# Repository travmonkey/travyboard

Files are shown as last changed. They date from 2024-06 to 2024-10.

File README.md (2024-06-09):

# travyboard

## A corne style keyboard with the Pico SDK and TinyUSB

A personal project demonstrating how to build a keyboard using the 
Raspberry Pi Pico microcontroller in c++.

### Requirements

- Two Raspberry Pi Picos
- Cmake and gcc/g++ installed. May want to set up wsl2 on Windows.
- Pico SDK [GitHub Repo](https://github.com/raspberrypi/pico-sdk)

### Setup

1. Clone the Pico SDK and update the submodules
```sh
git clone https://github.com/raspberrypi/pico-sdk.git
cd pico-sdk
git submodule update --init
```

2. Set an environment variable so cmake can find the sdk
```sh
export PICO_SDK_PATH=`<pico sdk path>`
```

3. Clone this repository:
```sh
git clone https://github.com/travmonkey/travyboard.git
cd travyboard
```

4. Create build folder and build the project:
```sh
cd firmware
mkdir build && cd build
cmake -DCMAKE_EXPORT_COMPILE_COMMANDS=ON .. # Export the compile commands for clangd to see
make
```

5. Mount and flash both picos with the master and slave compiled .uf2 code.
```sh
mkdir ~/rpi-pico
sudo fdisk -l # Find the pico device
sudo mount /dev/sdx1 /home/`<user>`/rpi-pico
sudo cp src/master.uf2 /home/`<user>`/rpi-pico/
```
Alternativly you can modify the script I wrote to include your own directories and username

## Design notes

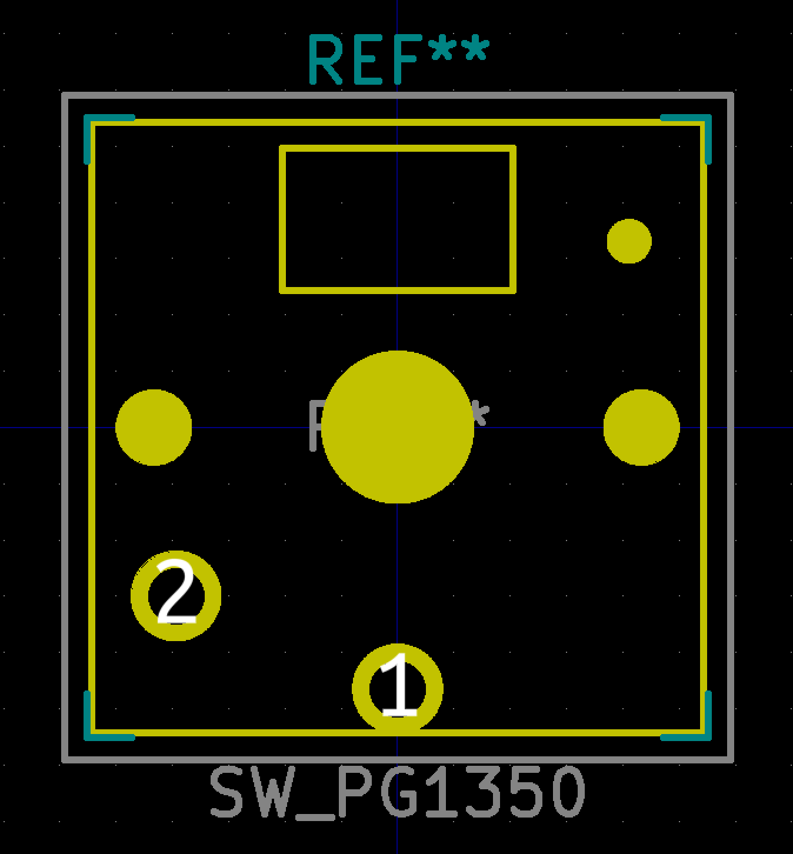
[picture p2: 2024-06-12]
pcb/symbols/keyswitches.pretty-2.1/images/SW_PG1350.png

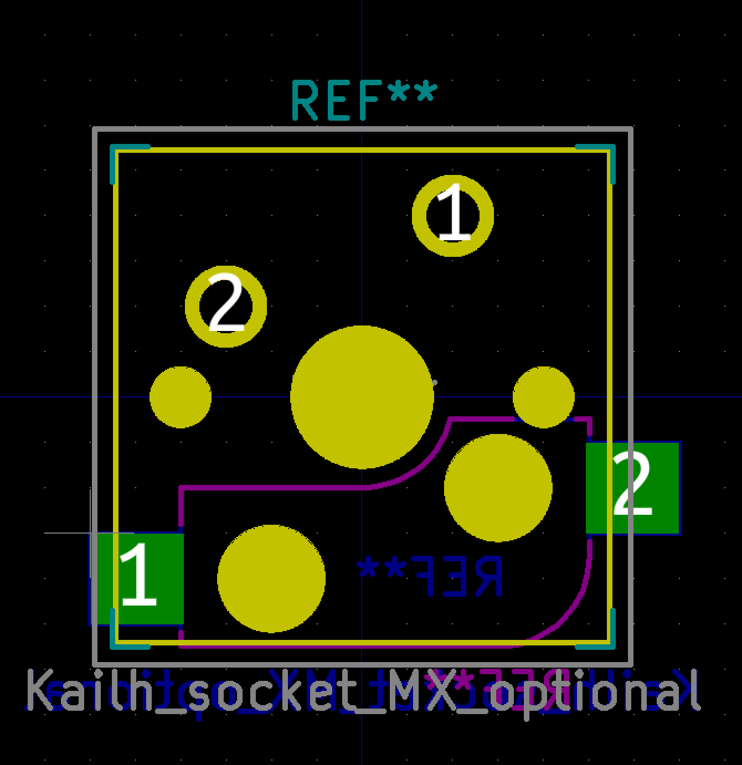
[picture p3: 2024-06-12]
pcb/symbols/keyswitches.pretty-2.1/images/Kailh_socket_MX_optional.png

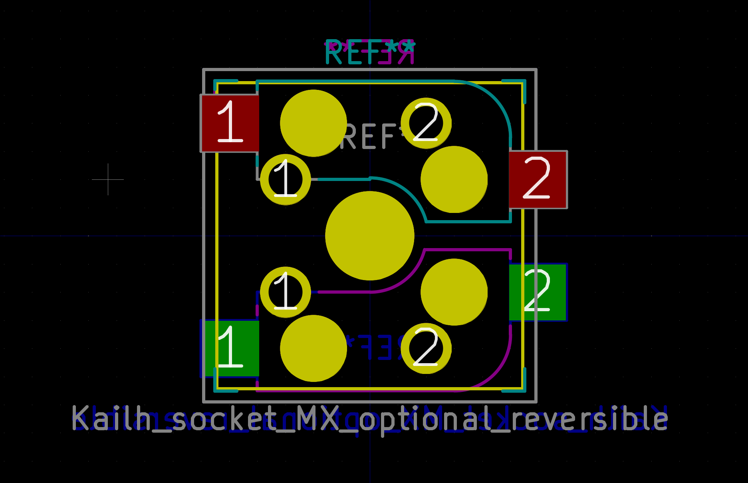
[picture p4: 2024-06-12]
pcb/symbols/keyswitches.pretty-2.1/images/Kailh_socket_MX_optional_reversible_platemount.png

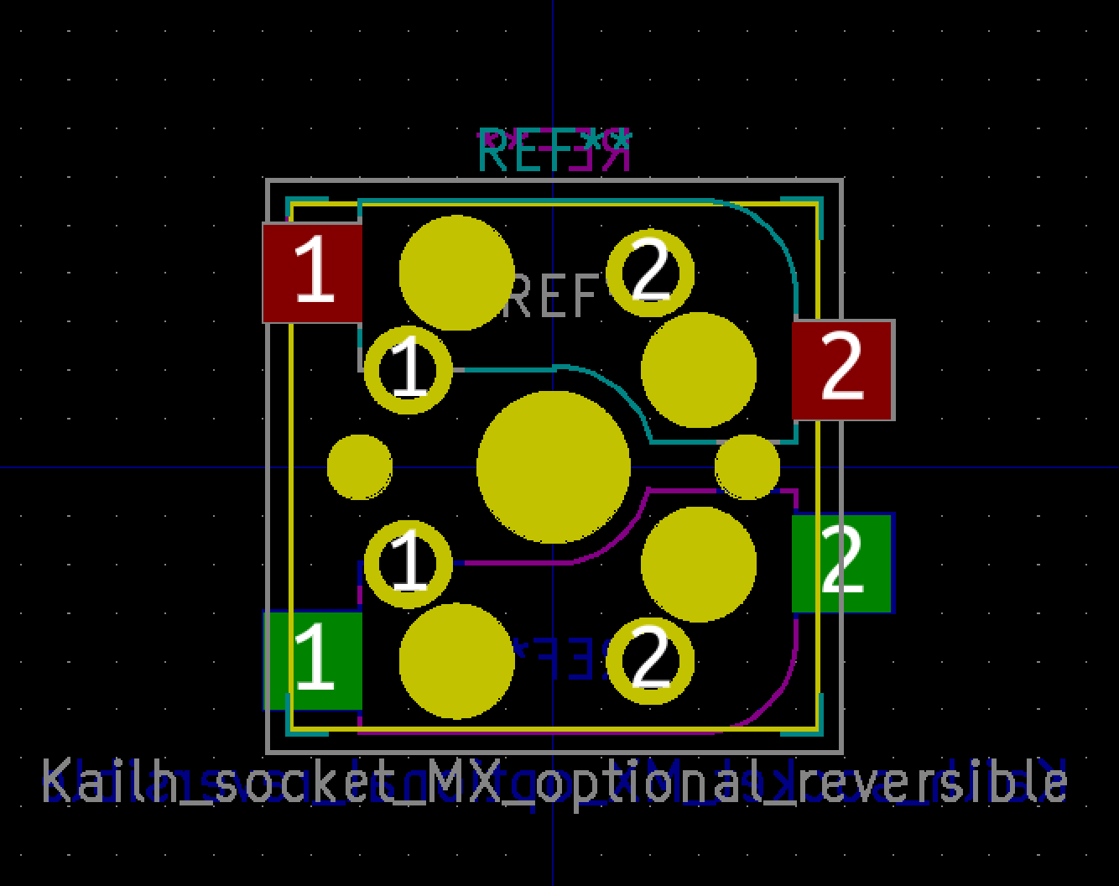
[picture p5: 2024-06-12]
pcb/symbols/keyswitches.pretty-2.1/images/Kailh_socket_MX_optional_reversible.png

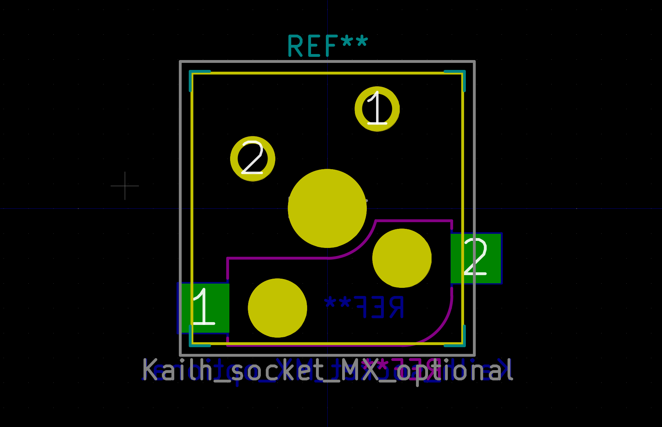
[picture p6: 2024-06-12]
pcb/symbols/keyswitches.pretty-2.1/images/Kailh_socket_MX_optional_platemount.png

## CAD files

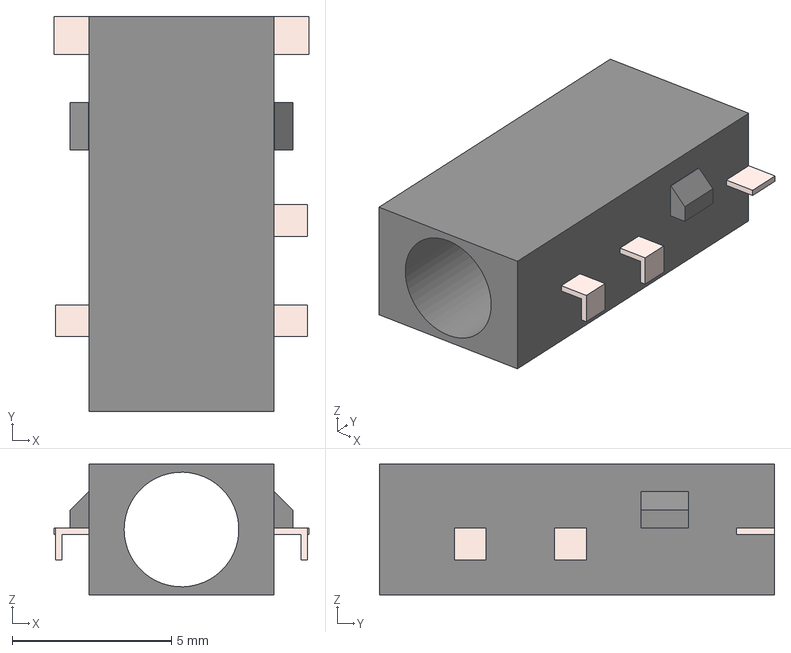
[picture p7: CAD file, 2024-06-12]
pcb/models/PJ-398A-5A.step
8.00 x 12.4 x 4.10 mm

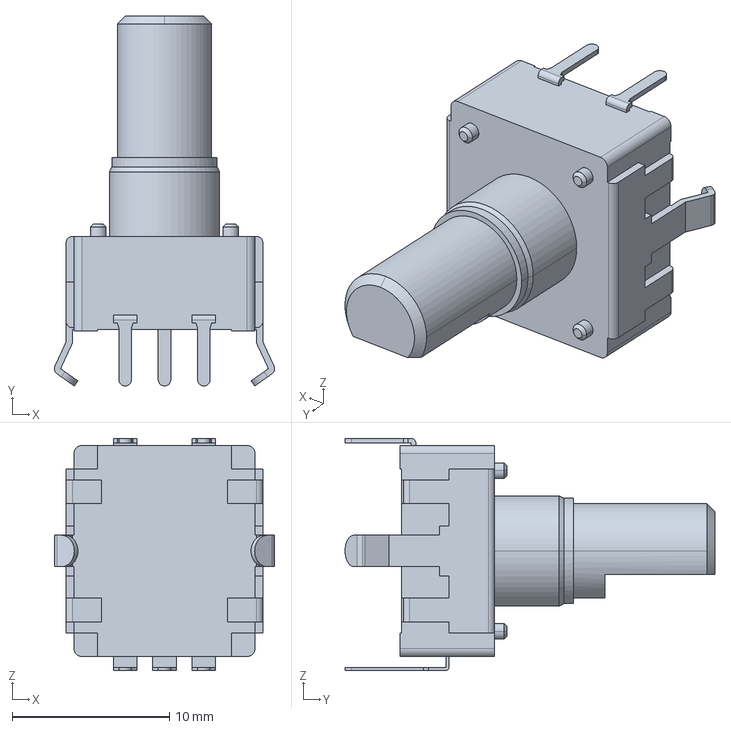
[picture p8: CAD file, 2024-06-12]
pcb/models/pec12r-4220f-s0024.stp
14.0 x 23.5 x 14.7 mm

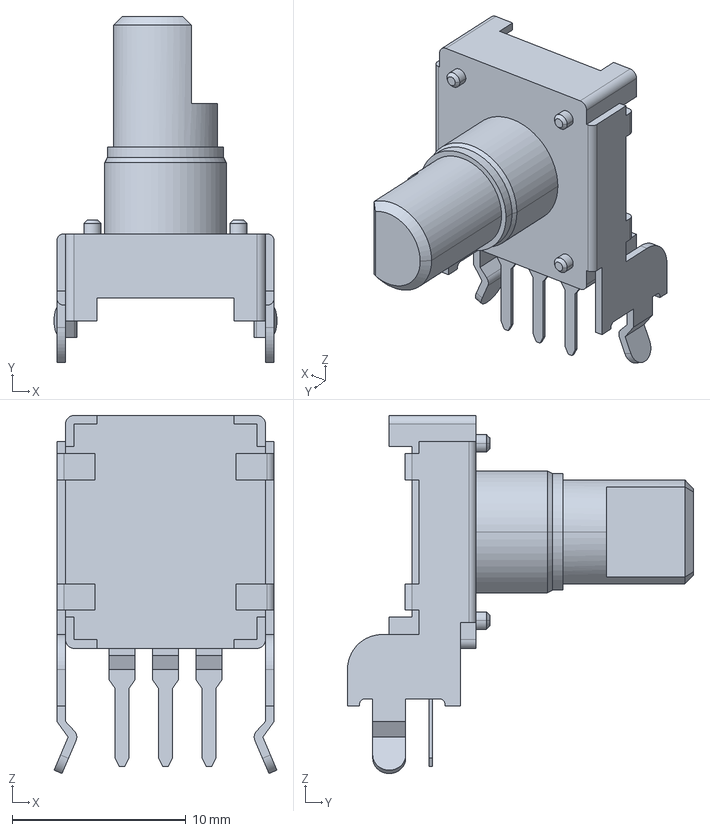
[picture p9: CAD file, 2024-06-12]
pcb/models/pec12r-2120f-s0012.stp
12.8 x 19.9 x 20.6 mm

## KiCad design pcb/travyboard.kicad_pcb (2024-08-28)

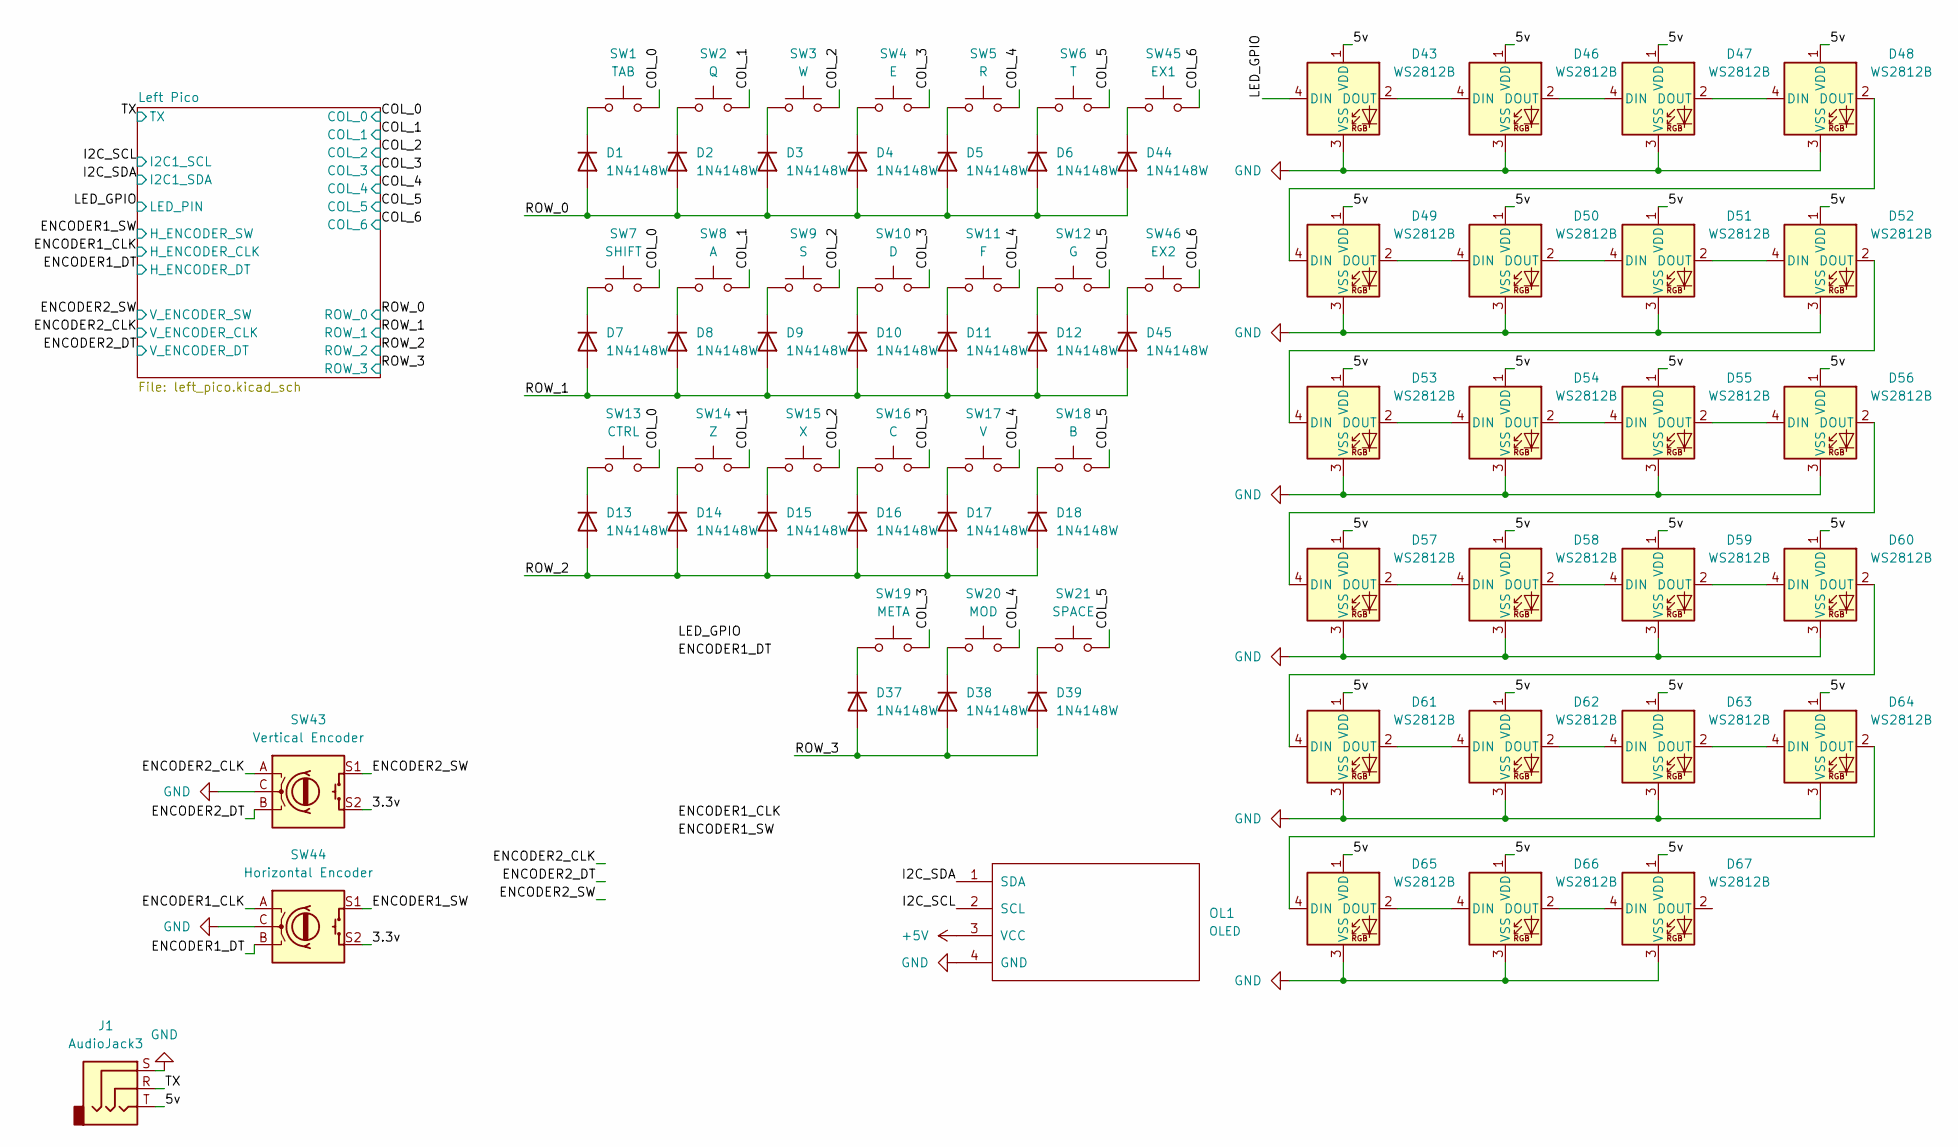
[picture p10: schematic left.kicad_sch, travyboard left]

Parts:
D1, D2, D3, D4, D5, D6, D7, D8, D9, D10, D11, D12, D13, D14, D15, D16, D17, D18, D37, D38, D39, D44, D45: 1N4148W; D_SOD-123
D43, D46, D47, D48, D49, D50, D51, D52, D53, D54, D55, D56, D57, D58, D59, D60, D61, D62, D63, D64, D65, D66, D67: WS2812B; LED_WS2812B_PLCC4_5.0x5.0mm_P3.2mm
J1: AudioJack3; PJ-399B-6A
OL1: OLED; SSD1306-0.91-OLED-4pin-128x32
SW1: TAB; CherryMX_Hotswap
SW2: Q; CherryMX_Hotswap
SW3: W; CherryMX_Hotswap
SW4: E; CherryMX_Hotswap
SW5: R; CherryMX_Hotswap
SW6: T; CherryMX_Hotswap
SW7: SHIFT; CherryMX_Hotswap
SW8: A; CherryMX_Hotswap
SW9: S; CherryMX_Hotswap
SW10: D; CherryMX_Hotswap
SW11: F; CherryMX_Hotswap
SW12: G; CherryMX_Hotswap
SW13: CTRL; CherryMX_Hotswap
SW14: Z; CherryMX_Hotswap
SW15: X; CherryMX_Hotswap
SW16: C; CherryMX_Hotswap
SW17: V; CherryMX_Hotswap
SW18: B; CherryMX_Hotswap
SW19: META; CherryMX_Hotswap
SW20: MOD; CherryMX_Hotswap
SW21: SPACE; CherryMX_Hotswap
SW43: Vertical Encoder; PEC12R-4220F-20024
SW44: Horizontal Encoder; PEC12R-2120F-S0012
SW45: EX1; CherryMX_Hotswap
SW46: EX2; CherryMX_Hotswap

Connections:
+5V: OL1.3 (VCC); also elsewhere on the board
/Left Half/3.3v: SW43.S2, SW44.S2
/Left Half/5v: D43.1 (VDD), D46.1 (VDD), D47.1 (VDD), D48.1 (VDD), D49.1 (VDD), D50.1 (VDD), D51.1 (VDD), D52.1 (VDD), D53.1 (VDD), D54.1 (VDD), D55.1 (VDD), D56.1 (VDD), D57.1 (VDD), D58.1 (VDD), D59.1 (VDD), D60.1 (VDD), D61.1 (VDD), D62.1 (VDD), D63.1 (VDD), D64.1 (VDD), D65.1 (VDD), D66.1 (VDD), D67.1 (VDD), J1.T
/Left Half/COL_0: SW1.2, SW7.2, SW13.2; also elsewhere on the board
/Left Half/COL_1: SW2.2, SW8.2, SW14.2; also elsewhere on the board
/Left Half/COL_2: SW3.2, SW9.2, SW15.2; also elsewhere on the board
/Left Half/COL_3: SW4.2, SW10.2, SW16.2, SW19.2; also elsewhere on the board
/Left Half/COL_4: SW5.2, SW11.2, SW17.2, SW20.2; also elsewhere on the board
/Left Half/COL_5: SW6.2, SW12.2, SW18.2, SW21.2; also elsewhere on the board
/Left Half/COL_6: SW45.2, SW46.2; also elsewhere on the board
/Left Half/ENCODER1_CLK: SW44.A; also elsewhere on the board
/Left Half/ENCODER1_DT: SW44.B; also elsewhere on the board
/Left Half/ENCODER1_SW: SW44.S1; also elsewhere on the board
/Left Half/ENCODER2_CLK: SW43.A; also elsewhere on the board
/Left Half/ENCODER2_DT: SW43.B; also elsewhere on the board
/Left Half/ENCODER2_SW: SW43.S1; also elsewhere on the board
/Left Half/I2C_SCL: OL1.2 (SCL); also elsewhere on the board
/Left Half/I2C_SDA: OL1.1 (SDA); also elsewhere on the board
/Left Half/LED_GPIO: D43.4 (DIN); also elsewhere on the board
/Left Half/ROW_0: D1.2 (A), D2.2 (A), D3.2 (A), D4.2 (A), D5.2 (A), D6.2 (A), D44.2 (A); also elsewhere on the board
/Left Half/ROW_1: D7.2 (A), D8.2 (A), D9.2 (A), D10.2 (A), D11.2 (A), D12.2 (A), D45.2 (A); also elsewhere on the board
/Left Half/ROW_2: D13.2 (A), D14.2 (A), D15.2 (A), D16.2 (A), D17.2 (A), D18.2 (A); also elsewhere on the board
/Left Half/ROW_3: D37.2 (A), D38.2 (A), D39.2 (A); also elsewhere on the board
/Left Half/TX: J1.R; also elsewhere on the board
GND: D43.3 (VSS), D46.3 (VSS), D47.3 (VSS), D48.3 (VSS), D49.3 (VSS), D50.3 (VSS), D51.3 (VSS), D52.3 (VSS), D53.3 (VSS), D54.3 (VSS), D55.3 (VSS), D56.3 (VSS), D57.3 (VSS), D58.3 (VSS), D59.3 (VSS), D60.3 (VSS), D61.3 (VSS), D62.3 (VSS), D63.3 (VSS), D64.3 (VSS), D65.3 (VSS), D66.3 (VSS), D67.3 (VSS), J1.S, OL1.4 (GND), SW43.C, SW44.C; also elsewhere on the board
unnamed: D1.1 (K), SW1.1
unnamed: D2.1 (K), SW2.1
unnamed: D3.1 (K), SW3.1
unnamed: D4.1 (K), SW4.1
unnamed: D5.1 (K), SW5.1
unnamed: D6.1 (K), SW6.1
unnamed: D7.1 (K), SW7.1
unnamed: D8.1 (K), SW8.1
unnamed: D9.1 (K), SW9.1
unnamed: D10.1 (K), SW10.1
unnamed: D11.1 (K), SW11.1
unnamed: D12.1 (K), SW12.1
unnamed: D13.1 (K), SW13.1
unnamed: D14.1 (K), SW14.1
unnamed: D15.1 (K), SW15.1
unnamed: D16.1 (K), SW16.1
unnamed: D17.1 (K), SW17.1
unnamed: D18.1 (K), SW18.1
unnamed: D37.1 (K), SW19.1
unnamed: D38.1 (K), SW20.1
unnamed: D39.1 (K), SW21.1
unnamed: D43.2 (DOUT), D46.4 (DIN)
unnamed: D44.1 (K), SW45.1
unnamed: D45.1 (K), SW46.1
unnamed: D46.2 (DOUT), D47.4 (DIN)
unnamed: D47.2 (DOUT), D48.4 (DIN)
unnamed: D48.2 (DOUT), D49.4 (DIN)
unnamed: D49.2 (DOUT), D50.4 (DIN)
unnamed: D50.2 (DOUT), D51.4 (DIN)
unnamed: D51.2 (DOUT), D52.4 (DIN)
unnamed: D52.2 (DOUT), D53.4 (DIN)
unnamed: D53.2 (DOUT), D54.4 (DIN)
unnamed: D54.2 (DOUT), D55.4 (DIN)
unnamed: D55.2 (DOUT), D56.4 (DIN)
unnamed: D56.2 (DOUT), D57.4 (DIN)
unnamed: D57.2 (DOUT), D58.4 (DIN)
unnamed: D58.2 (DOUT), D59.4 (DIN)
unnamed: D59.2 (DOUT), D60.4 (DIN)
unnamed: D60.2 (DOUT), D61.4 (DIN)
unnamed: D61.2 (DOUT), D62.4 (DIN)
unnamed: D62.2 (DOUT), D63.4 (DIN)
unnamed: D63.2 (DOUT), D64.4 (DIN)
unnamed: D64.2 (DOUT), D65.4 (DIN)
unnamed: D65.2 (DOUT), D66.4 (DIN)
unnamed: D66.2 (DOUT), D67.4 (DIN)

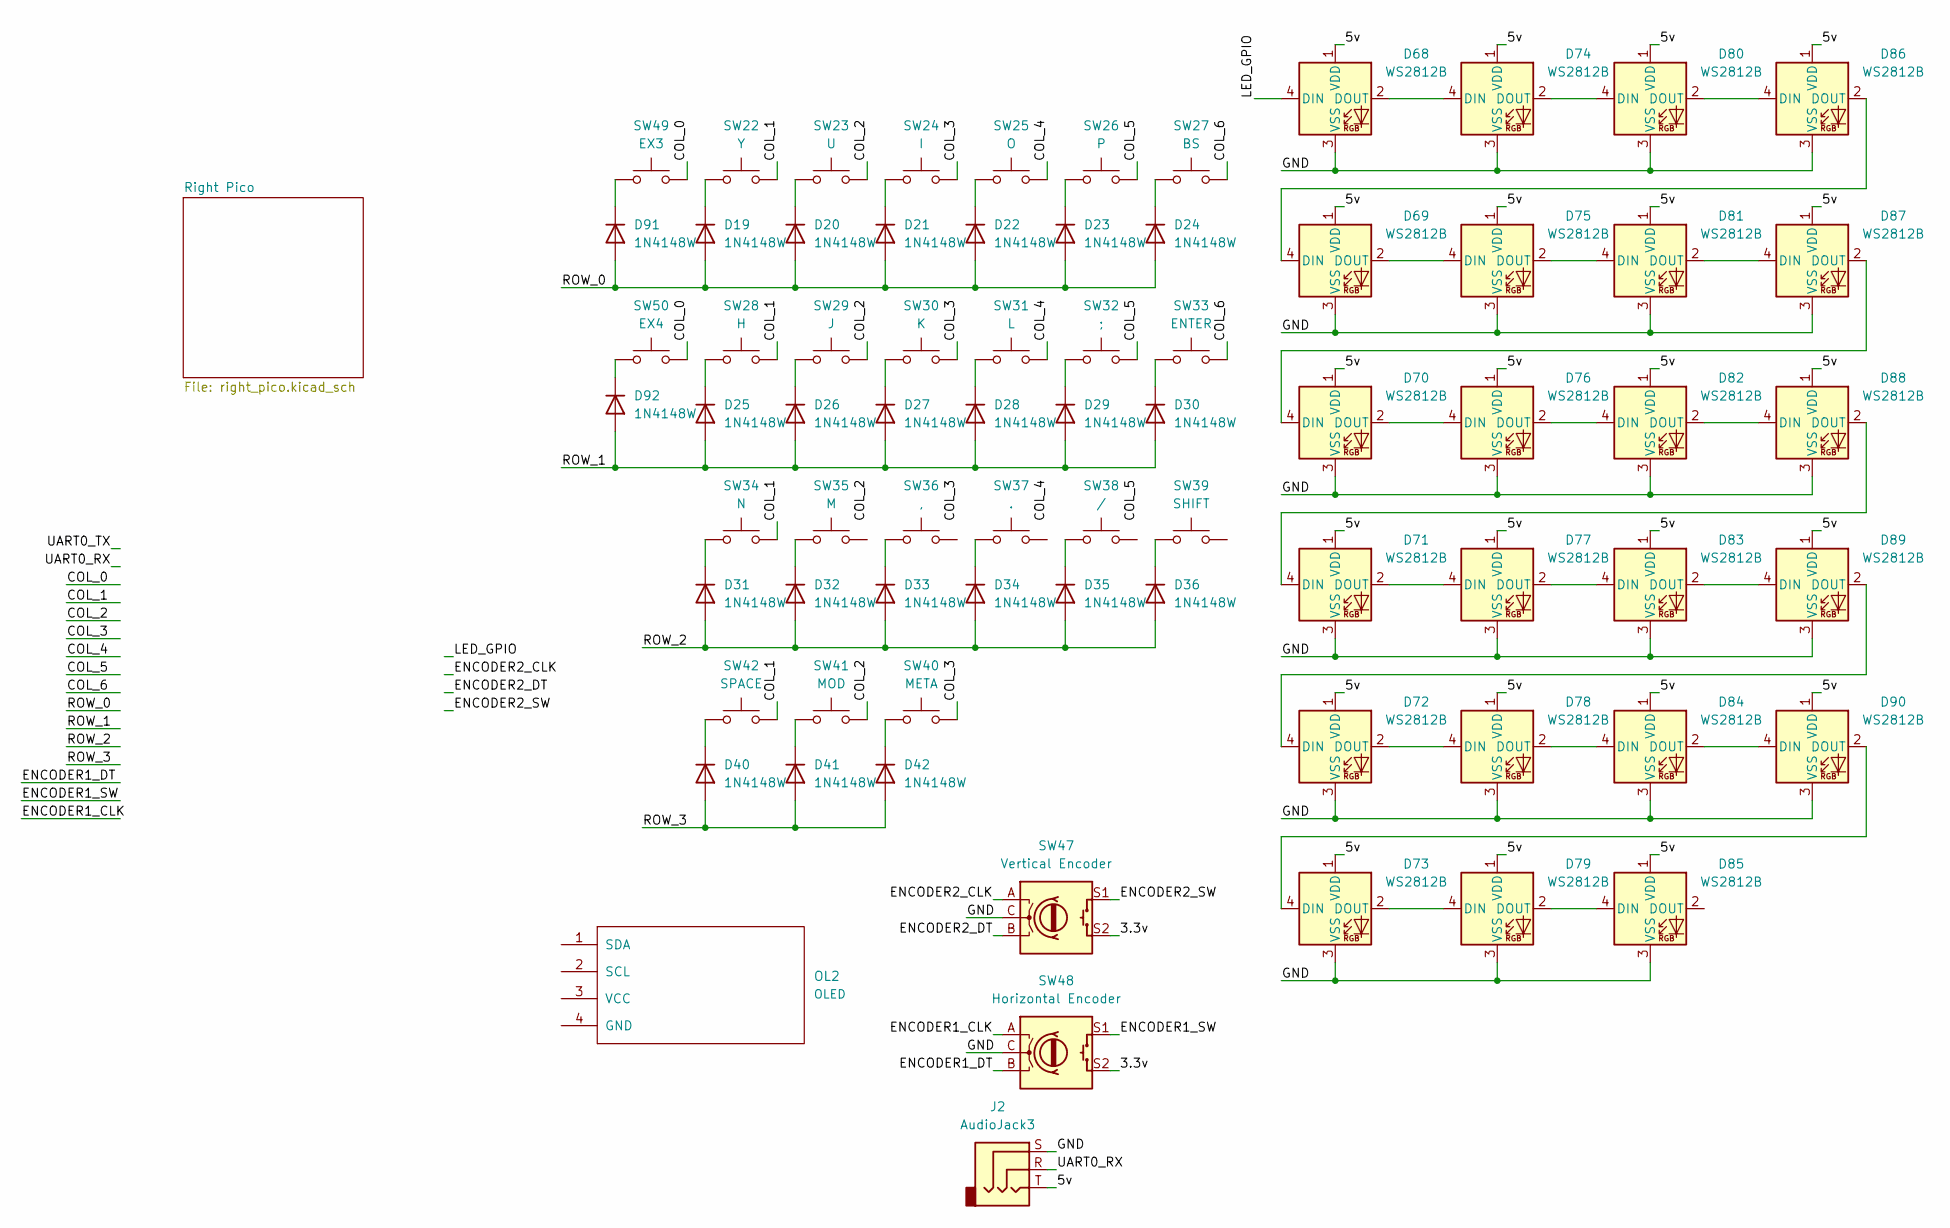
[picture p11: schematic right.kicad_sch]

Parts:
D19, D20, D21, D22, D23, D24, D25, D26, D27, D28, D29, D30, D31, D32, D33, D34, D35, D36, D40, D41, D42, D91, D92: 1N4148W; D_SOD-123
D68, D69, D70, D71, D72, D73, D74, D75, D76, D77, D78, D79, D80, D81, D82, D83, D84, D85, D86, D87, D88, D89, D90: WS2812B; LED_WS2812B_PLCC4_5.0x5.0mm_P3.2mm
J2: AudioJack3; PJ-399B-6A
OL2: OLED; SSD1306-0.91-OLED-4pin-128x32
SW22: Y; CherryMX_Hotswap
SW23: U; CherryMX_Hotswap
SW24: I; CherryMX_Hotswap
SW25: O; CherryMX_Hotswap
SW26: P; CherryMX_Hotswap
SW27: BS; CherryMX_Hotswap
SW28: H; CherryMX_Hotswap
SW29: J; CherryMX_Hotswap
SW30: K; CherryMX_Hotswap
SW31: L; CherryMX_Hotswap
SW32: ;; CherryMX_Hotswap
SW33: ENTER; CherryMX_Hotswap
SW34: N; CherryMX_Hotswap
SW35: M; CherryMX_Hotswap
SW36: ,; CherryMX_Hotswap
SW37: .; CherryMX_Hotswap
SW38: /; CherryMX_Hotswap
SW39: SHIFT; CherryMX_Hotswap
SW40: META; CherryMX_Hotswap
SW41: MOD; CherryMX_Hotswap
SW42: SPACE; CherryMX_Hotswap
SW47: Vertical Encoder; PEC12R-4220F-20024
SW48: Horizontal Encoder; PEC12R-2120F-S0012
SW49: EX3; CherryMX_Hotswap
SW50: EX4; CherryMX_Hotswap

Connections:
/Right Half/3.3v: SW47.S2, SW48.S2
/Right Half/5v: D68.1 (VDD), D69.1 (VDD), D70.1 (VDD), D71.1 (VDD), D72.1 (VDD), D73.1 (VDD), D74.1 (VDD), D75.1 (VDD), D76.1 (VDD), D77.1 (VDD), D78.1 (VDD), D79.1 (VDD), D80.1 (VDD), D81.1 (VDD), D82.1 (VDD), D83.1 (VDD), D84.1 (VDD), D85.1 (VDD), D86.1 (VDD), D87.1 (VDD), D88.1 (VDD), D89.1 (VDD), D90.1 (VDD), J2.T
/Right Half/COL_0: SW49.2, SW50.2
/Right Half/COL_1: SW22.2, SW28.2, SW34.2, SW42.2
/Right Half/COL_2: SW23.2, SW29.2, SW41.2
/Right Half/COL_3: SW24.2, SW30.2, SW40.2
/Right Half/COL_4: SW25.2, SW31.2
/Right Half/COL_5: SW26.2, SW32.2
/Right Half/COL_6: SW27.2, SW33.2
/Right Half/ENCODER1_CLK: SW48.A
/Right Half/ENCODER1_DT: SW48.B
/Right Half/ENCODER1_SW: SW48.S1
/Right Half/ENCODER2_CLK: SW47.A
/Right Half/ENCODER2_DT: SW47.B
/Right Half/ENCODER2_SW: SW47.S1
/Right Half/GND: D68.3 (VSS), D69.3 (VSS), D70.3 (VSS), D71.3 (VSS), D72.3 (VSS), D73.3 (VSS), D74.3 (VSS), D75.3 (VSS), D76.3 (VSS), D77.3 (VSS), D78.3 (VSS), D79.3 (VSS), D80.3 (VSS), D81.3 (VSS), D82.3 (VSS), D83.3 (VSS), D84.3 (VSS), D85.3 (VSS), D86.3 (VSS), D87.3 (VSS), D88.3 (VSS), D89.3 (VSS), D90.3 (VSS), J2.S, SW47.C, SW48.C
/Right Half/LED_GPIO: D68.4 (DIN)
/Right Half/ROW_0: D19.2 (A), D20.2 (A), D21.2 (A), D22.2 (A), D23.2 (A), D24.2 (A), D91.2 (A)
/Right Half/ROW_1: D25.2 (A), D26.2 (A), D27.2 (A), D28.2 (A), D29.2 (A), D30.2 (A), D92.2 (A)
/Right Half/ROW_2: D31.2 (A), D32.2 (A), D33.2 (A), D34.2 (A), D35.2 (A), D36.2 (A)
/Right Half/ROW_3: D40.2 (A), D41.2 (A), D42.2 (A)
/Right Half/UART0_RX: J2.R
unnamed: D19.1 (K), SW22.1
unnamed: D20.1 (K), SW23.1
unnamed: D21.1 (K), SW24.1
unnamed: D22.1 (K), SW25.1
unnamed: D23.1 (K), SW26.1
unnamed: D24.1 (K), SW27.1
unnamed: D25.1 (K), SW28.1
unnamed: D26.1 (K), SW29.1
unnamed: D27.1 (K), SW30.1
unnamed: D28.1 (K), SW31.1
unnamed: D29.1 (K), SW32.1
unnamed: D30.1 (K), SW33.1
unnamed: D31.1 (K), SW34.1
unnamed: D32.1 (K), SW35.1
unnamed: D33.1 (K), SW36.1
unnamed: D34.1 (K), SW37.1
unnamed: D35.1 (K), SW38.1
unnamed: D36.1 (K), SW39.1
unnamed: D40.1 (K), SW42.1
unnamed: D41.1 (K), SW41.1
unnamed: D42.1 (K), SW40.1
unnamed: D68.2 (DOUT), D74.4 (DIN)
unnamed: D69.4 (DIN), D86.2 (DOUT)
unnamed: D69.2 (DOUT), D75.4 (DIN)
unnamed: D70.4 (DIN), D87.2 (DOUT)
unnamed: D70.2 (DOUT), D76.4 (DIN)
unnamed: D71.4 (DIN), D88.2 (DOUT)
unnamed: D71.2 (DOUT), D77.4 (DIN)
unnamed: D72.4 (DIN), D89.2 (DOUT)
unnamed: D72.2 (DOUT), D78.4 (DIN)
unnamed: D73.4 (DIN), D90.2 (DOUT)
unnamed: D73.2 (DOUT), D79.4 (DIN)
unnamed: D74.2 (DOUT), D80.4 (DIN)
unnamed: D75.2 (DOUT), D81.4 (DIN)
unnamed: D76.2 (DOUT), D82.4 (DIN)
unnamed: D77.2 (DOUT), D83.4 (DIN)
unnamed: D78.2 (DOUT), D84.4 (DIN)
unnamed: D79.2 (DOUT), D85.4 (DIN)
unnamed: D80.2 (DOUT), D86.4 (DIN)
unnamed: D81.2 (DOUT), D87.4 (DIN)
unnamed: D82.2 (DOUT), D88.4 (DIN)
unnamed: D83.2 (DOUT), D89.4 (DIN)
unnamed: D84.2 (DOUT), D90.4 (DIN)
unnamed: D91.1 (K), SW49.1
unnamed: D92.1 (K), SW50.1

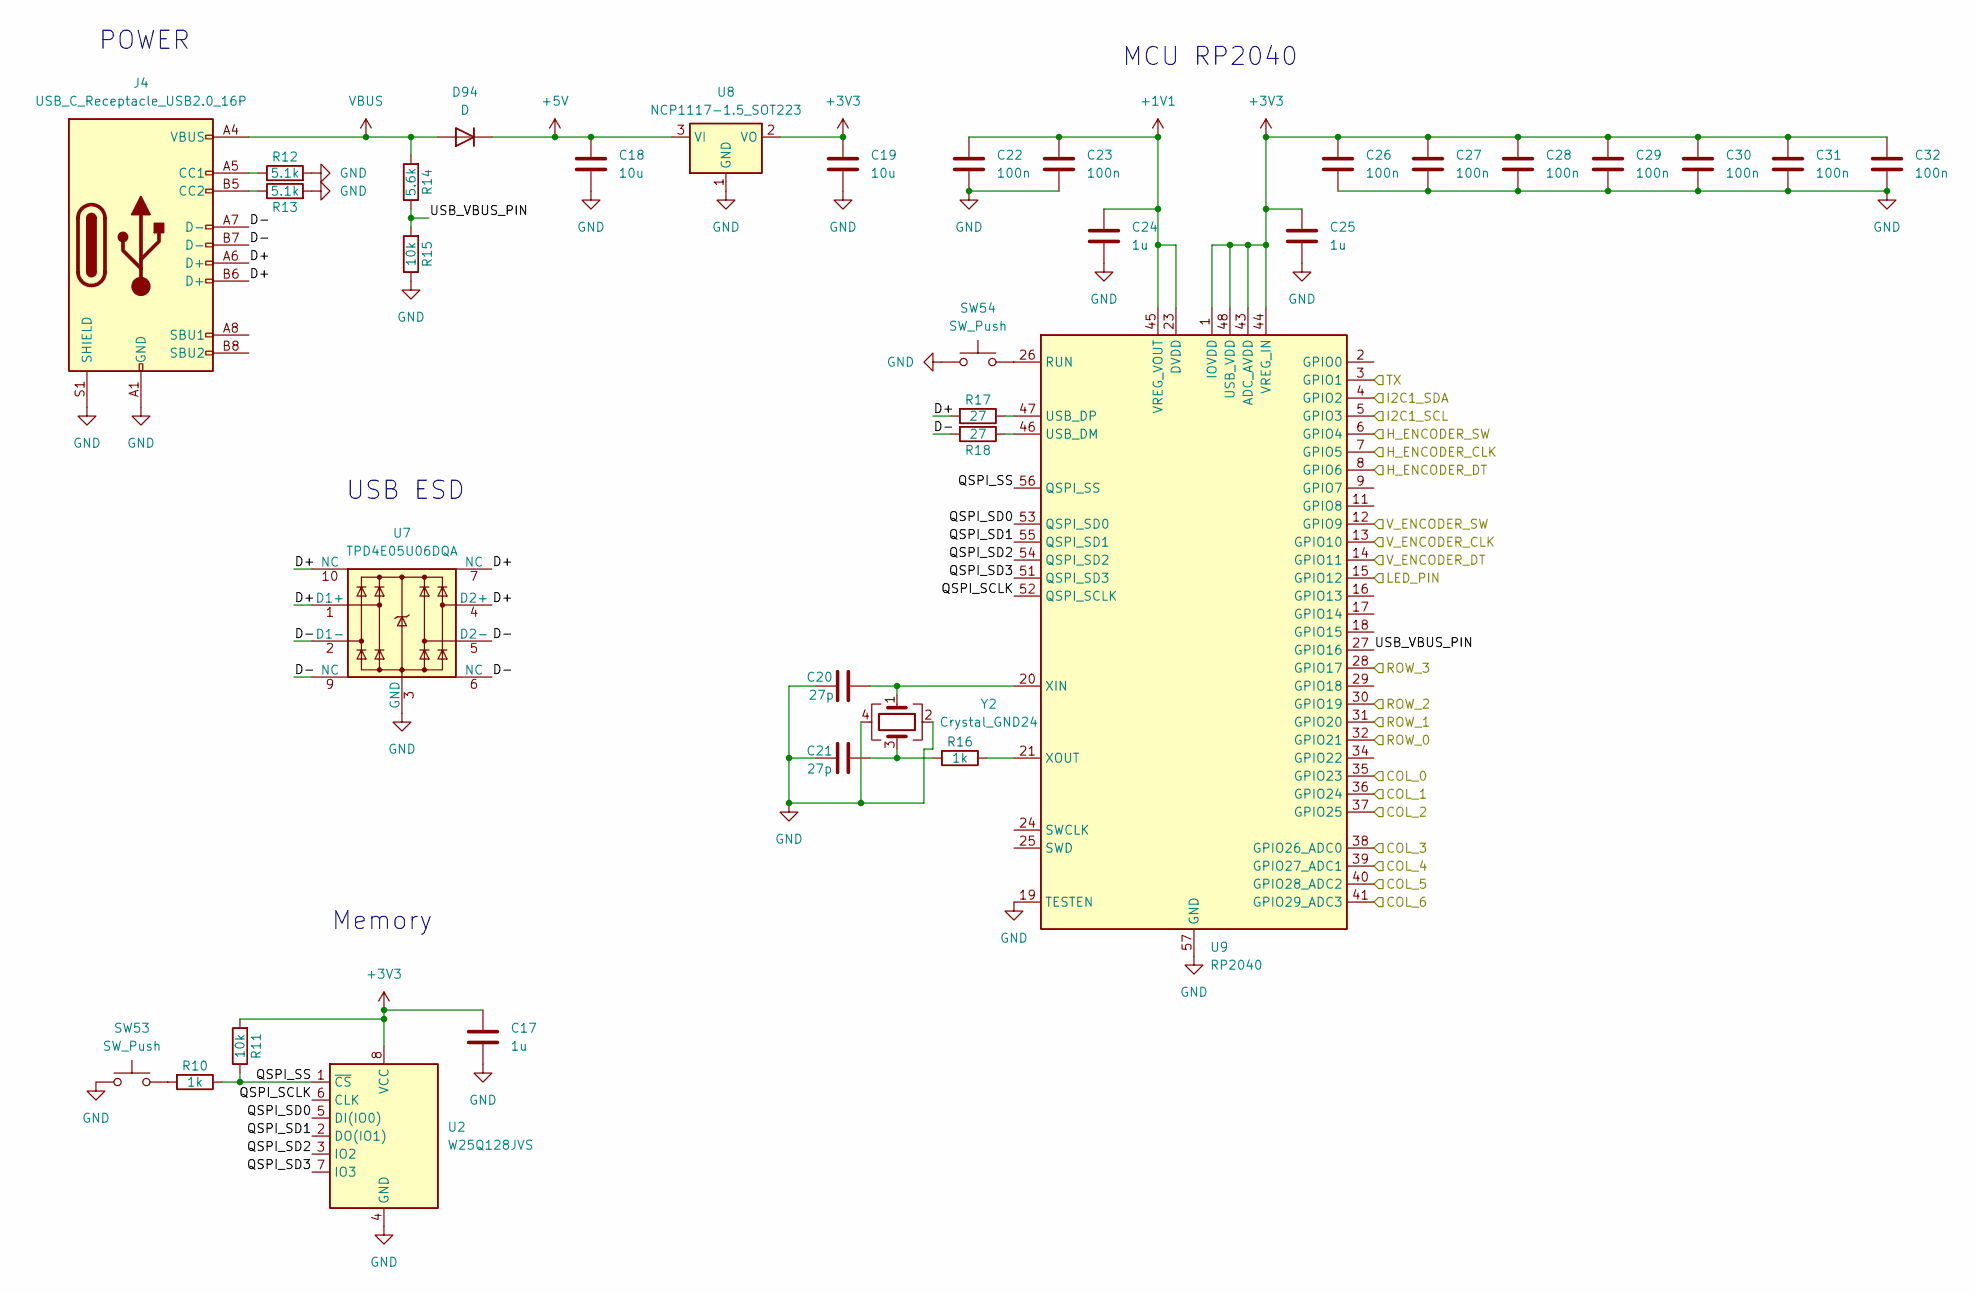
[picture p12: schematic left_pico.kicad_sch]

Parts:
C17, C24, C25: 1u; C_0402_1005Metric
C18, C19: 10u; C_0402_1005Metric
C20, C21: 27p; C_0402_1005Metric
C22, C23, C26, C27, C28, C29, C30, C31, C32: 100n; C_0402_1005Metric
D94: D; D_SOD-523
J4: USB_C_Receptacle_USB2.0_16P; TYPE-C-31-M-13C
R10, R16: 1k; R_0402_1005Metric
R11, R15: 10k; R_0402_1005Metric
R12, R13: 5.1k; R_0402_1005Metric
R14: 5.6k; R_0402_1005Metric
R17, R18: 27; R_0402_1005Metric
SW53, SW54: SW_Push
U2: W25Q128JVS; SOIC-8_5.23x5.23mm_P1.27mm
U7: TPD4E05U06DQA; USON-10_2.5x1.0mm_P0.5mm
U8: NCP1117-1.5_SOT223; SOT-223-3_TabPin2
U9: RP2040; QFN-56-1EP_7x7mm_P0.4mm_EP3.2x3.2mm
Y2: Crystal_GND24; Crystal_SMD_3225-4Pin_3.2x2.5mm

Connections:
+1V1: C22.1, C23.1, C24.1, U9.23 (DVDD), U9.45 (VREG_VOUT), U9.50 (DVDD); also elsewhere on the board
+3V3: C17.1, C19.1, C25.1, C26.1, C27.1, C28.1, C29.1, C30.1, C31.1, C32.1, R11.2, U2.8 (VCC), U8.2 (VO), U9.1 (IOVDD), U9.10 (IOVDD), U9.22 (IOVDD), U9.33 (IOVDD), U9.42 (IOVDD), U9.43 (ADC_AVDD), U9.44 (VREG_IN), U9.48 (USB_VDD), U9.49 (IOVDD); also elsewhere on the board
+5V: C18.1, D94.1 (K), U8.3 (VI); also elsewhere on the board
/Left Half/COL_0: U9.35 (GPIO23); also elsewhere on the board
/Left Half/COL_1: U9.36 (GPIO24); also elsewhere on the board
/Left Half/COL_2: U9.37 (GPIO25); also elsewhere on the board
/Left Half/COL_3: U9.38 (GPIO26_ADC0); also elsewhere on the board
/Left Half/COL_4: U9.39 (GPIO27_ADC1); also elsewhere on the board
/Left Half/COL_5: U9.40 (GPIO28_ADC2); also elsewhere on the board
/Left Half/COL_6: U9.41 (GPIO29_ADC3); also elsewhere on the board
/Left Half/ENCODER1_CLK: U9.7 (GPIO5); also elsewhere on the board
/Left Half/ENCODER1_DT: U9.8 (GPIO6); also elsewhere on the board
/Left Half/ENCODER1_SW: U9.6 (GPIO4); also elsewhere on the board
/Left Half/ENCODER2_CLK: U9.13 (GPIO10); also elsewhere on the board
/Left Half/ENCODER2_DT: U9.14 (GPIO11); also elsewhere on the board
/Left Half/ENCODER2_SW: U9.12 (GPIO9); also elsewhere on the board
/Left Half/I2C_SCL: U9.5 (GPIO3); also elsewhere on the board
/Left Half/I2C_SDA: U9.4 (GPIO2); also elsewhere on the board
/Left Half/LED_GPIO: U9.15 (GPIO12); also elsewhere on the board
/Left Half/Left Pico/D+: J4.A6 (D+), J4.B6 (D+), R17.2, U7.1 (D1+), U7.4 (D2+), U7.7 (NC), U7.10 (NC)
/Left Half/Left Pico/D-: J4.A7 (D-), J4.B7 (D-), R18.2, U7.2 (D1-), U7.5 (D2-), U7.6 (NC), U7.9 (NC)
/Left Half/Left Pico/QSPI_SCLK: U2.6 (CLK), U9.52 (QSPI_SCLK)
/Left Half/Left Pico/QSPI_SD0: U2.5 (DI(IO0)), U9.53 (QSPI_SD0)
/Left Half/Left Pico/QSPI_SD1: U2.2 (DO(IO1)), U9.55 (QSPI_SD1)
/Left Half/Left Pico/QSPI_SD2: U2.3 (IO2), U9.54 (QSPI_SD2)
/Left Half/Left Pico/QSPI_SD3: U2.7 (IO3), U9.51 (QSPI_SD3)
/Left Half/Left Pico/QSPI_SS: R10.1, R11.1, U2.1 (~CS), U9.56 (QSPI_SS)
/Left Half/Left Pico/USB_VBUS_PIN: R14.1, R15.2, U9.27 (GPIO16)
/Left Half/ROW_0: U9.32 (GPIO21); also elsewhere on the board
/Left Half/ROW_1: U9.31 (GPIO20); also elsewhere on the board
/Left Half/ROW_2: U9.30 (GPIO19); also elsewhere on the board
/Left Half/ROW_3: U9.28 (GPIO17); also elsewhere on the board
/Left Half/TX: U9.3 (GPIO1); also elsewhere on the board
GND: C17.2, C18.2, C19.2, C20.1, C21.1, C22.2, C23.2, C24.2, C25.2, C26.2, C27.2, C28.2, C29.2, C30.2, C31.2, C32.2, J4.A1 (GND), J4.A12 (GND), J4.B1 (GND), J4.B12 (GND), J4.S1 (SHIELD), R12.2, R13.2, R15.1, SW53.1, SW54.1, U2.4 (GND), U7.3 (GND), U7.8 (GND), U8.1 (GND), U9.19 (TESTEN), U9.57 (GND), Y2.2, Y2.4; also elsewhere on the board
unnamed: C21.2, R16.2, Y2.3
unnamed: J4.A5 (CC1), R12.1
unnamed: J4.B5 (CC2), R13.1
unnamed: R10.2, SW53.2
unnamed: SW54.2, U9.26 (RUN)
unnamed: R18.1, U9.46 (USB_DM)
unnamed: R17.1, U9.47 (USB_DP)
unnamed: C20.2, U9.20 (XIN), Y2.1
unnamed: R16.1, U9.21 (XOUT)
VBUS: D94.2 (A), J4.A4 (VBUS), J4.A9 (VBUS), J4.B4 (VBUS), J4.B9 (VBUS), R14.2; also elsewhere on the board

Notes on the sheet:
USB ESD
MCU RP2040
POWER
Memory

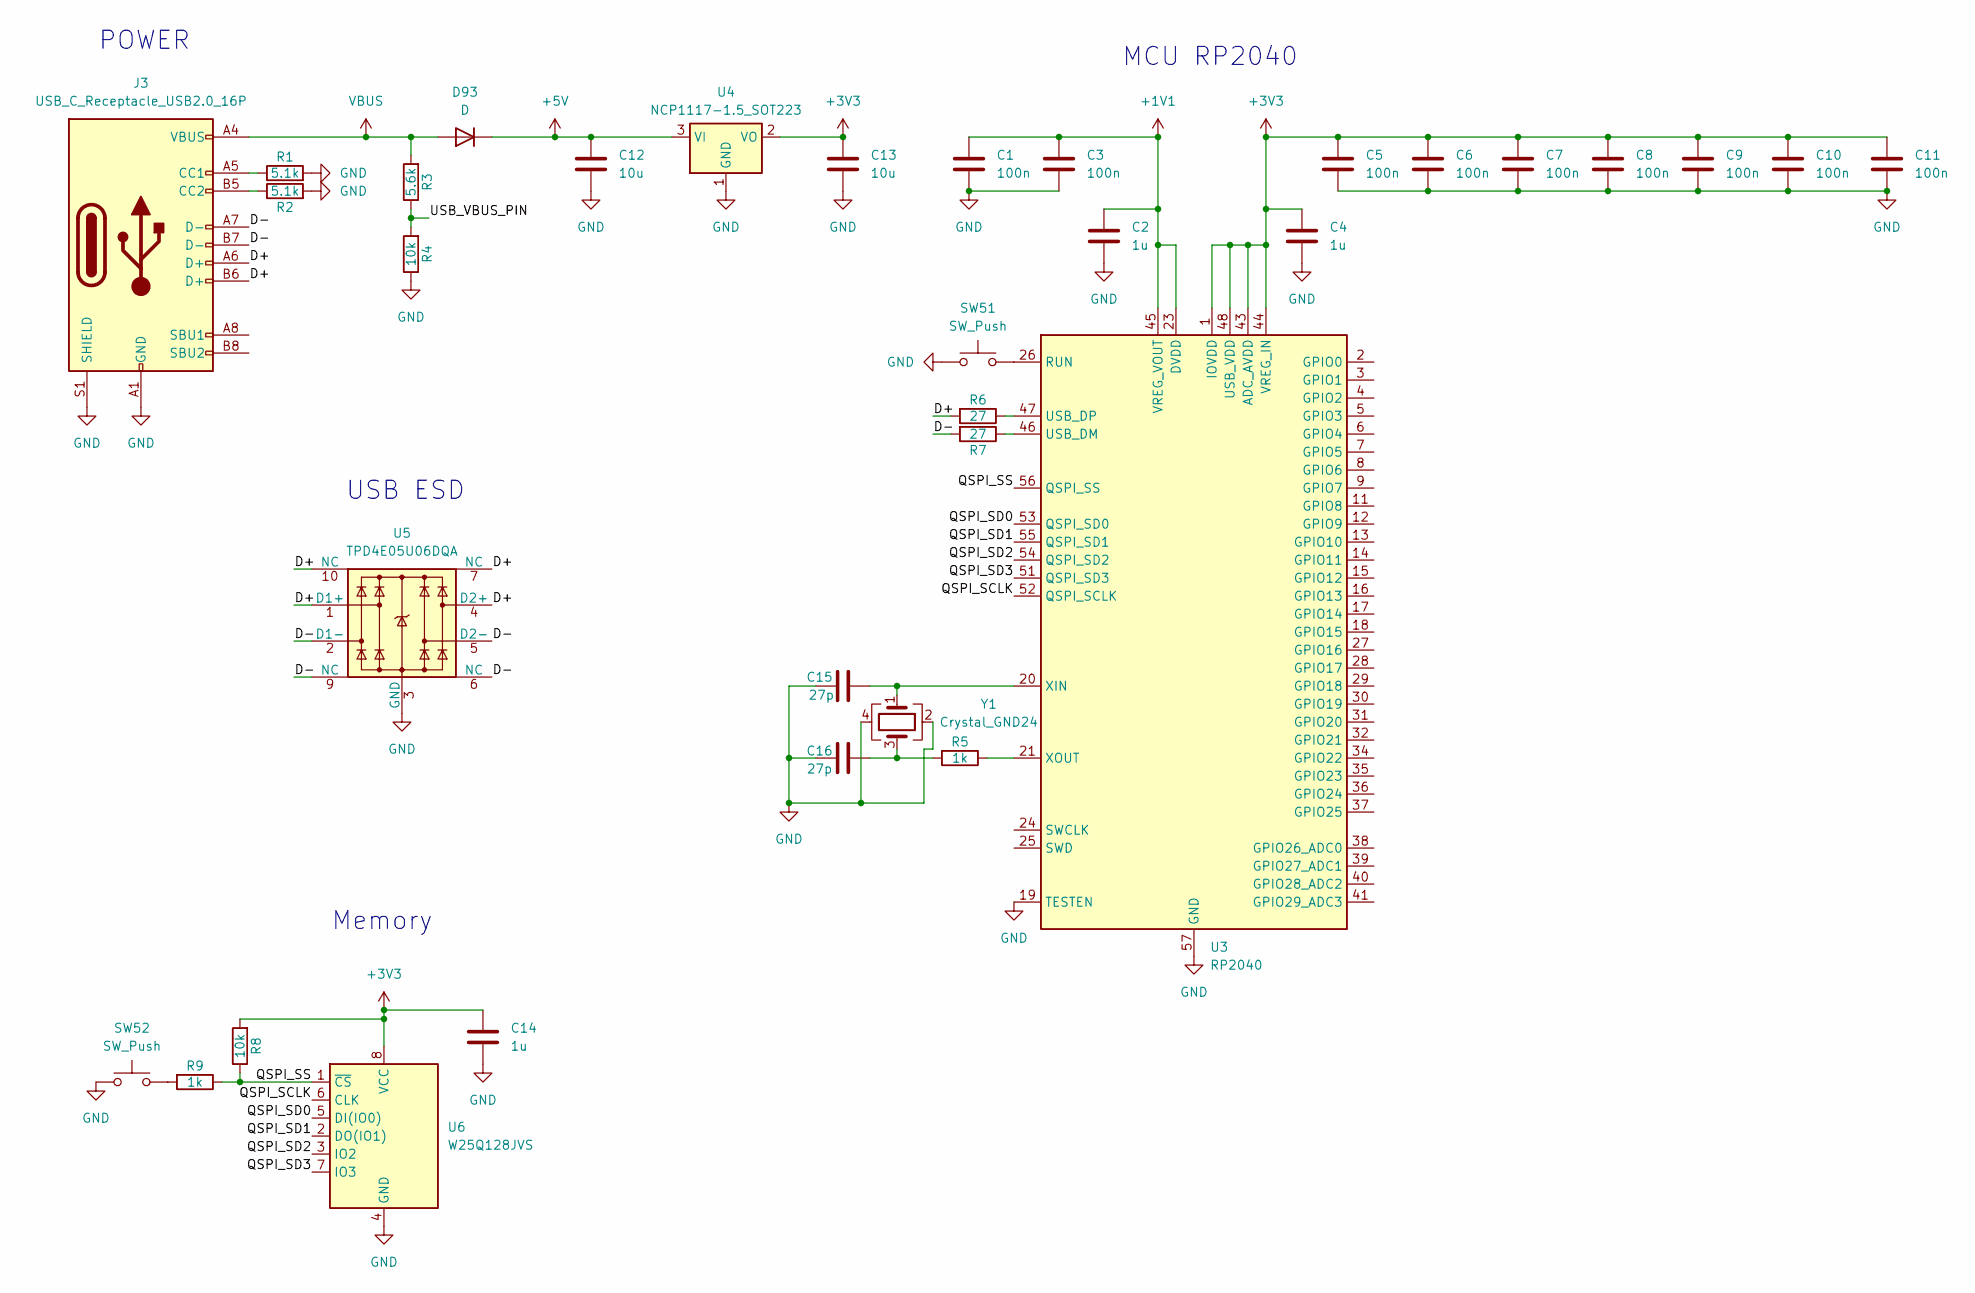
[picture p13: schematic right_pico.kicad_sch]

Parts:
C1, C3, C5, C6, C7, C8, C9, C10, C11: 100n; C_0402_1005Metric
C2, C4, C14: 1u; C_0402_1005Metric
C12, C13: 10u; C_0402_1005Metric
C15, C16: 27p; C_0402_1005Metric
D93: D; D_SOD-523
J3: USB_C_Receptacle_USB2.0_16P; TYPE-C-31-M-13C
R1, R2: 5.1k; R_0402_1005Metric
R3: 5.6k; R_0402_1005Metric
R4, R8: 10k; R_0402_1005Metric
R5, R9: 1k; R_0402_1005Metric
R6, R7: 27; R_0402_1005Metric
SW51, SW52: SW_Push
U3: RP2040; QFN-56-1EP_7x7mm_P0.4mm_EP3.2x3.2mm
U4: NCP1117-1.5_SOT223; SOT-223-3_TabPin2
U5: TPD4E05U06DQA; USON-10_2.5x1.0mm_P0.5mm
U6: W25Q128JVS; SOIC-8_5.23x5.23mm_P1.27mm
Y1: Crystal_GND24; Crystal_SMD_3225-4Pin_3.2x2.5mm

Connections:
+1V1: C1.1, C2.1, C3.1, U3.23 (DVDD), U3.45 (VREG_VOUT), U3.50 (DVDD); also elsewhere on the board
+3V3: C4.1, C5.1, C6.1, C7.1, C8.1, C9.1, C10.1, C11.1, C13.1, C14.1, R8.2, U3.1 (IOVDD), U3.10 (IOVDD), U3.22 (IOVDD), U3.33 (IOVDD), U3.42 (IOVDD), U3.43 (ADC_AVDD), U3.44 (VREG_IN), U3.48 (USB_VDD), U3.49 (IOVDD), U4.2 (VO), U6.8 (VCC); also elsewhere on the board
+5V: C12.1, D93.1 (K), U4.3 (VI); also elsewhere on the board
/Right Half/Right Pico/D+: J3.A6 (D+), J3.B6 (D+), R6.2, U5.1 (D1+), U5.4 (D2+), U5.7 (NC), U5.10 (NC)
/Right Half/Right Pico/D-: J3.A7 (D-), J3.B7 (D-), R7.2, U5.2 (D1-), U5.5 (D2-), U5.6 (NC), U5.9 (NC)
/Right Half/Right Pico/QSPI_SCLK: U3.52 (QSPI_SCLK), U6.6 (CLK)
/Right Half/Right Pico/QSPI_SD0: U3.53 (QSPI_SD0), U6.5 (DI(IO0))
/Right Half/Right Pico/QSPI_SD1: U3.55 (QSPI_SD1), U6.2 (DO(IO1))
/Right Half/Right Pico/QSPI_SD2: U3.54 (QSPI_SD2), U6.3 (IO2)
/Right Half/Right Pico/QSPI_SD3: U3.51 (QSPI_SD3), U6.7 (IO3)
/Right Half/Right Pico/QSPI_SS: R8.1, R9.1, U3.56 (QSPI_SS), U6.1 (~CS)
/Right Half/Right Pico/USB_VBUS_PIN: R3.1, R4.2
GND: C1.2, C2.2, C3.2, C4.2, C5.2, C6.2, C7.2, C8.2, C9.2, C10.2, C11.2, C12.2, C13.2, C14.2, C15.1, C16.1, J3.A1 (GND), J3.A12 (GND), J3.B1 (GND), J3.B12 (GND), J3.S1 (SHIELD), R1.2, R2.2, R4.1, SW51.1, SW52.1, U3.19 (TESTEN), U3.57 (GND), U4.1 (GND), U5.3 (GND), U5.8 (GND), U6.4 (GND), Y1.2, Y1.4; also elsewhere on the board
unnamed: C16.2, R5.2, Y1.3
unnamed: J3.A5 (CC1), R1.1
unnamed: J3.B5 (CC2), R2.1
unnamed: R9.2, SW52.2
unnamed: SW51.2, U3.26 (RUN)
unnamed: R7.1, U3.46 (USB_DM)
unnamed: R6.1, U3.47 (USB_DP)
unnamed: C15.2, U3.20 (XIN), Y1.1
unnamed: R5.1, U3.21 (XOUT)
VBUS: D93.2 (A), J3.A4 (VBUS), J3.A9 (VBUS), J3.B4 (VBUS), J3.B9 (VBUS), R3.2; also elsewhere on the board

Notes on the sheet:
POWER
USB ESD
Memory
MCU RP2040

Board: 2 copper layers, 210 parts (125 on the bottom side), 164 nets, no tracks yet.

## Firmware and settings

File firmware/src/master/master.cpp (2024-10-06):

/*
 * The MIT License (MIT)
 *
 * Copyright (c) 2019 Ha Thach (tinyusb.org)
 *
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
 */

#include "bsp/board_api.h"
#include "class/hid/hid.h"
#include "class/hid/hid_device.h"
#include "hardware/gpio.h"
#include "hardware/uart.h"
#include "tusb.h"

#include "encoder.hpp"
#include "keyboard.hpp"
#include "usb_descriptors.h"
#include <cstdint>

//--------------------------------------------------------------------+
// MACRO CONSTANT TYPEDEF PROTYPES
//--------------------------------------------------------------------+

// Blink pattern
enum {
  BLINK_NOT_MOUNTED = 250, // device not mounted
  BLINK_MOUNTED = 1000,    // device mounted
  BLINK_SUSPENDED = 2500,  // device is suspended
};

enum {
  LEFT = 0,
  RIGHT = 1
};

// Blink pattern
static uint32_t blink_interval_ms = BLINK_NOT_MOUNTED;

void led_blinking_task(void); // define function prototype

KeyBoard keyboard(RIGHT); // create right keyboard object

// Create rotary encoders
RotaryEncoder horizontal_encoder(9, 8, 7);

// Function to initialize uart
void uart_init() {
  uart_init(UART_ID, BAUD_RATE);
  // gpio_set_function(UART_TX_PIN, GPIO_FUNC_UART);
  gpio_set_function(UART_RX_PIN, GPIO_FUNC_UART);
}

void send_mouse_report(int8_t vertical, int8_t horizontal) {
  // Poll every 1ms
  const uint32_t interval_ms = 1;
  static uint32_t start_ms = 0;

  // Check for time since last poll
  if (board_millis() - start_ms < interval_ms) {
    return; // not enough time
  }
  start_ms += interval_ms;
  if (!tud_hid_ready())
    return;

  tud_hid_mouse_report(REPORT_ID_MOUSE, 0x00, vertical, horizontal, 0, 0);
}

/*------------- MAIN -------------*/
int main(void) {
  // Initialize the board and TinyUsb
  board_init();
  tusb_init();
  uart_init();

  gpio_init(2);
  gpio_set_dir(2, GPIO_OUT);
  gpio_put(2, false);

  while (true) {
    tud_task(); // tinyusb device task

    // Task to manage the blinking of the onboard LED
    led_blinking_task();
    keyboard.scan_buttons();
    int encoder_position = horizontal_encoder.get_position();
    if (encoder_position > 0) {
      send_mouse_report(0, -15);
    } else if (encoder_position < 0) {
      send_mouse_report(0, 15);
    }
    horizontal_encoder.reset_position();
  }

  return 0;
}

//--------------------------------------------------------------------+
// USB HID TINYUSB FUNCTIONS
//--------------------------------------------------------------------+

// Invoked when sent REPORT successfully to host
// Application can use this to send the next report
// Note: For composite reports, report[0] is report ID
void tud_hid_report_complete_cb(uint8_t instance, uint8_t const *report,
                                uint8_t len) {
  // not implemented, we only send REPORT_ID_KEYBOARD
  (void)instance;
  (void)len;
}

// Invoked when received GET_REPORT control request
// Application must fill buffer report's content and return its length.
// Return zero will cause the stack to STALL request
uint16_t tud_hid_get_report_cb(uint8_t instance, uint8_t report_id,
                               hid_report_type_t report_type, uint8_t *buffer,
                               uint16_t reqlen) {
  // TODO not Implemented
  (void)instance;
  (void)report_id;
  (void)report_type;
  (void)buffer;
  (void)reqlen;

  return 0;
}

// Invoked when received SET_REPORT control request or
// received data on OUT endpoint ( Report ID = 0, Type = 0 )
void tud_hid_set_report_cb(uint8_t instance, uint8_t report_id,
                           hid_report_type_t report_type, uint8_t const *buffer,
                           uint16_t bufsize) {
  (void)instance;

  if (report_type == HID_REPORT_TYPE_OUTPUT) {
    // Set keyboard LED e.g Capslock, Numlock etc...
    if (report_id == REPORT_ID_KEYBOARD) {
      // bufsize should be (at least) 1
      if (bufsize < 1)
        return;

      uint8_t const kbd_leds = buffer[0];

      if (kbd_leds & KEYBOARD_LED_CAPSLOCK) {
        // Capslock On: disable blink, turn led on
        blink_interval_ms = 0;
        board_led_write(true);
      } else {
        // Caplocks Off: back to normal blink
        board_led_write(false);
        blink_interval_ms = BLINK_MOUNTED;
      }
    }
  }
}

//--------------------------------------------------------------------+
// Device callbacks
//--------------------------------------------------------------------+

// Invoked when device is mounted
void tud_mount_cb(void) { blink_interval_ms = BLINK_MOUNTED; }

// Invoked when device is unmounted
void tud_umount_cb(void) { blink_interval_ms = BLINK_NOT_MOUNTED; }

// Invoked when usb bus is suspended
// remote_wakeup_en : if host allow us  to perform remote wakeup
// Within 7ms, device must draw an average of current less than 2.5 mA from
// bus
void tud_suspend_cb(bool remote_wakeup_en) {
  (void)remote_wakeup_en;
  blink_interval_ms = BLINK_SUSPENDED;
}

// Invoked when usb bus is resumed
void tud_resume_cb(void) { blink_interval_ms = BLINK_MOUNTED; }

//--------------------------------------------------------------------+
// BLINKING TASK
//--------------------------------------------------------------------+
void led_blinking_task(void) {
  static uint32_t start_ms = 0;
  static bool led_state = false;

  // blink is disabled
  if (!blink_interval_ms)
    return;

  // Blink every interval ms
  if (board_millis() - start_ms < blink_interval_ms)
    return; // not enough time
  start_ms += blink_interval_ms;

  board_led_write(led_state);
  led_state = 1 - led_state; // toggle
}

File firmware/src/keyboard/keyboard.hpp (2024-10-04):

// travmonkey

#ifndef KEYBOARD_H
#define KEYBOARD_H

#include <cstdint>
#include <string>

#define LEFT_MOD_ROW_PIN 15
#define LEFT_MOD_COLUMN_PIN 13
#define RIGHT_MOD_ROW_PIN 15
#define RIGHT_MOD_COLUMN_PIN 11

#define NULL_VALUE 255

#define DEBOUNCE_TIME 15

// Uart definitions
#define UART_ID uart0
#define BAUD_RATE 115200
#define UART_TX_PIN 0
#define UART_RX_PIN 1

// Left and Right half definitions, out of index for possible key array
#define LEFT_HALF 253
#define RIGHT_HALF 254

// LEGENDARY JADEN CROW SOLUTION
struct KeyPress {
  uint8_t row;
  uint8_t col;

  KeyPress() : row(NULL_VALUE), col(NULL_VALUE) {}
};

struct Keys {
  KeyPress location[6];
  Keys() {
    for (int i = 0; i < 6; i++) {
      location[i] = KeyPress();
    }
  }
  KeyPress &operator[](int i) { return location[i]; };
};

class KeyBoard {
private:
  uint8_t set_mod_layer(void);

  void handle_uart(void);

  void button_handler(uint8_t row, uint8_t col, char half);

  void send_keyboard_report(uint8_t layer);

  uint8_t check_layer(void);

  void refresh(void);

  constexpr static uint8_t LEFT_ROW_PINS[2] = {14, 15};
  constexpr static uint8_t LEFT_COLUMN_PINS[3] = {11, 12, 13};
  constexpr static uint8_t RIGHT_ROW_PINS[2] = {14, 15};
  constexpr static uint8_t RIGHT_COLUMN_PINS[3] = {11, 12, 13};

public:
  KeyBoard(const std::int8_t &name);
  void scan_buttons(void);
  Keys scan_pins(void);
};

#endif // KEYBOARD_H

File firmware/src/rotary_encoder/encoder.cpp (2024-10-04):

// travmonkey

#include "encoder.hpp"
#include "bsp/board.h"
#include "class/hid/hid_device.h"
#include "hardware/gpio.h"
#include "pico/types.h"
#include "usb_descriptors.h"
#include <cstdint>

#define DEBOUNCE_DELAY 5

RotaryEncoder::RotaryEncoder(uint clk, uint dt, uint sw)
    : ENCODER_CLK(clk), ENCODER_DT(dt), ENCODER_SW(sw) {

  // Create self variable for isr handling
  instance = this;

  // Initialize encoder pins and pull them up
  gpio_init(ENCODER_CLK);
  gpio_set_dir(ENCODER_CLK, GPIO_IN);
  gpio_disable_pulls(ENCODER_CLK);

  gpio_init(ENCODER_DT);
  gpio_set_dir(ENCODER_DT, GPIO_IN);
  gpio_disable_pulls(ENCODER_DT);

  gpio_init(ENCODER_SW);
  gpio_set_dir(ENCODER_SW, GPIO_IN);
  gpio_disable_pulls(ENCODER_SW);

  // Initialize callback handling
  gpio_set_irq_enabled_with_callback(ENCODER_CLK, GPIO_IRQ_EDGE_FALL, true,
                                     &RotaryEncoder::gpio_isr_handler);
  gpio_set_irq_enabled(ENCODER_SW, GPIO_IRQ_EDGE_FALL, true);
  gpio_set_irq_enabled(ENCODER_DT, GPIO_IRQ_EDGE_FALL, true);
};

RotaryEncoder *RotaryEncoder::instance = nullptr;

// Send current instance to handle interrupts
void RotaryEncoder::gpio_isr_handler(uint gpio, uint32_t events) {
  if (instance) {
    instance->handle_interrupt(gpio, events);
  }
}

// Handle rotary encoder interrupts
void RotaryEncoder::handle_interrupt(uint gpio, uint32_t events) {
  uint8_t current_time = board_millis();

  if (current_time - last_interrupt_time < DEBOUNCE_DELAY) {
    return; // ignore this interrupt from debouncing
  };
  last_interrupt_time = current_time; // update last interrupt time
  
  static int last_encoded = 0;
  static const int enc_states[] = {0,  -1, 1, 0, 1, 0, 0,  -1,
                                   -1, 0,  0, 1, 0, 1, -1, 0};

  int MSB = gpio_get(ENCODER_CLK);
  int LSB = gpio_get(ENCODER_DT);
  int encoded = (MSB << 1) | LSB;
  int sum = (last_encoded << 2) | encoded;
  encoder_pos += enc_states[sum & 0b1111];
  last_encoded = encoded;
}

void RotaryEncoder::listen() {
  const uint32_t interval_ms = 10;
  static uint32_t start_ms = 0;

  if (board_millis() - start_ms < interval_ms) {
    return; // not enough time
  }
  start_ms += interval_ms;

  if (!tud_hid_ready()) {
    return;
  }

  uint8_t current_dir[6] = {0};

  if (encoder_pos > 0) {
    current_dir[0] = 0x80;
    tud_hid_keyboard_report(REPORT_ID_KEYBOARD, 0, current_dir);
  } else if (encoder_pos < 0) {
    current_dir[0] = 0x81;
    tud_hid_keyboard_report(REPORT_ID_KEYBOARD, 0, current_dir);
  }
}

// Function to return encoder position
int RotaryEncoder::get_position() { return encoder_pos; }

// Function to reset encoder position
void RotaryEncoder::reset_position() { encoder_pos = 0; }

// Function to return button clicks on encoder
bool RotaryEncoder::button_clicked() {
  if (gpio_get(ENCODER_SW) == 0) {
    return true;
  } else {
    return false;
  }
}

// Add more functions here

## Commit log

2024-06-07 Initialize pico environment
2024-06-09 Create diode matrix
2024-06-09 Enable rotary encoder support
2024-06-09 Move encoder to namespace and create header
2024-06-12 Add initial circuit board design
    [left.kicad_sch, pec12r-2120f-s0012.stp, pec12r-4220f-s0024.stp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]
2024-06-12 Add jack 3d model
    [PJ-398A-5A.step]
2024-06-12 Wire left half of pcb
    [left.kicad_sch, travyboard.kicad_pcb]
2024-06-12 Move rotary encoder to class
2024-06-13 Add keymap code and basic uart functionality
2024-06-13 Rewire left half
    [left.kicad_sch, right.kicad_sch]
2024-06-16 Move row and column to start with 0 on schematic
    [left.kicad_sch, right.kicad_sch]
2024-06-17 Add basic uart keysending functionality
2024-06-18 Make Uart send keypresses
2024-06-18 Update pcb
2024-06-18 Fully functional UART key transmission
2024-06-19 Move uart handling to own function
2024-06-22 Switch to RP2040 chip on board
    [left.kicad_sch, left_pico.kicad_sch, right.kicad_sch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]
2024-08-28 Mouse and encoder testing
2024-08-28 Various changes
    [travyboard.kicad_pcb]
2024-10-04 Fix comparing string with int
    [keyboard.cpp, keyboard.hpp, master.cpp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]
2024-10-04 Implement debouncing on rotary encoder
2024-10-06 Change declaration for board.h
